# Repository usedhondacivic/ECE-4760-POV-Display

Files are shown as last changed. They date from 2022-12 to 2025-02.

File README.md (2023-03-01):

# ECE-4760 Final Project: Persistence of Vision Display
A persistence of vision display constructed from scratch using the Raspberry Pi Pico W microcontroller. Runs at 30 FPS with full RGB color and streams images over wifi.

Created by: Michael Crum (mmc323@cornell.edu), Joseph Horwitz (jah569@cornell.edu), Rabail Makhdoom (rm857@cornell.edu)

Read the write up: https://michael-crum.com/pov_display/

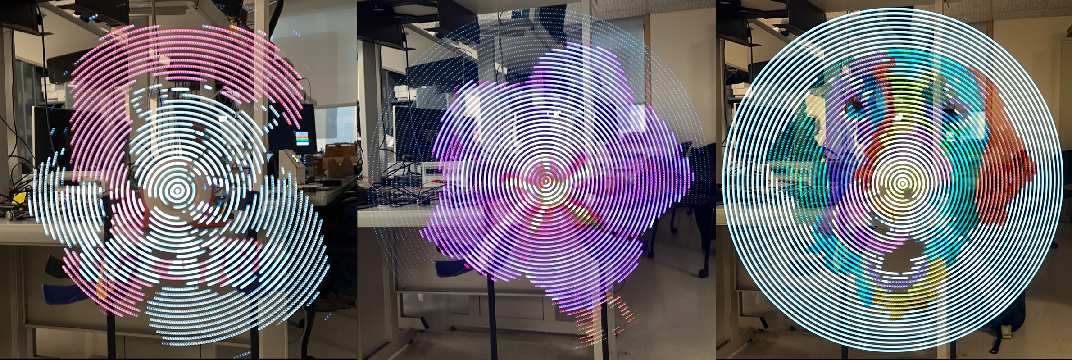
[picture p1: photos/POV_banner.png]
Three examples of the POV Display running


Project structure:
 - /PICO
	 - main.c
		 - Code entry point on the pico
	 - /drivers/apa102
		- Driver for the SPI based APA102 LEDs
	 - /utils/picow_tcp_client.c
		 - Driver for the TCP client
 - /PYTHON
	 - wifi.py
		 - TCP server for sending image data
- /new_python
	- New experimental python setup, including a browser based interface and support for most image types including gif's
	- web_server.py
		- Entry point for the program, launches the webserver which serves the web interface on localhost port 8080 (localhost:8080 in your web browser)
	- tcp_server.py
		- Handles connecting to the display over TCP, and sending arbitry data over the connection
	- file_translation.py
		- Translates image data to a radial RGB format used by the display
	- display_driver.py
		- Handles the transition from a file name to the proper byte format, then sends packets to the display using functions from tcp_server.py
	-  index.html
		- The html file served by the browser client in web_server.py

 - /HARDWARE
	 - /CAD
		 - STL files for 3D printing the mechanical structure
	 - /ELECTRICAL
		 - KiCad project files for the rotor and control board PCBs

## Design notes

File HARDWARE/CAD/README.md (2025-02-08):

Public onshape file is here: https://cad.onshape.com/documents/17b541f123296cb1e64515a7/w/77f36ce16f101784798e0ec6/e/821b7ccc222bb8b1a8efb6eb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

Fusion files are in super_structure.f3d

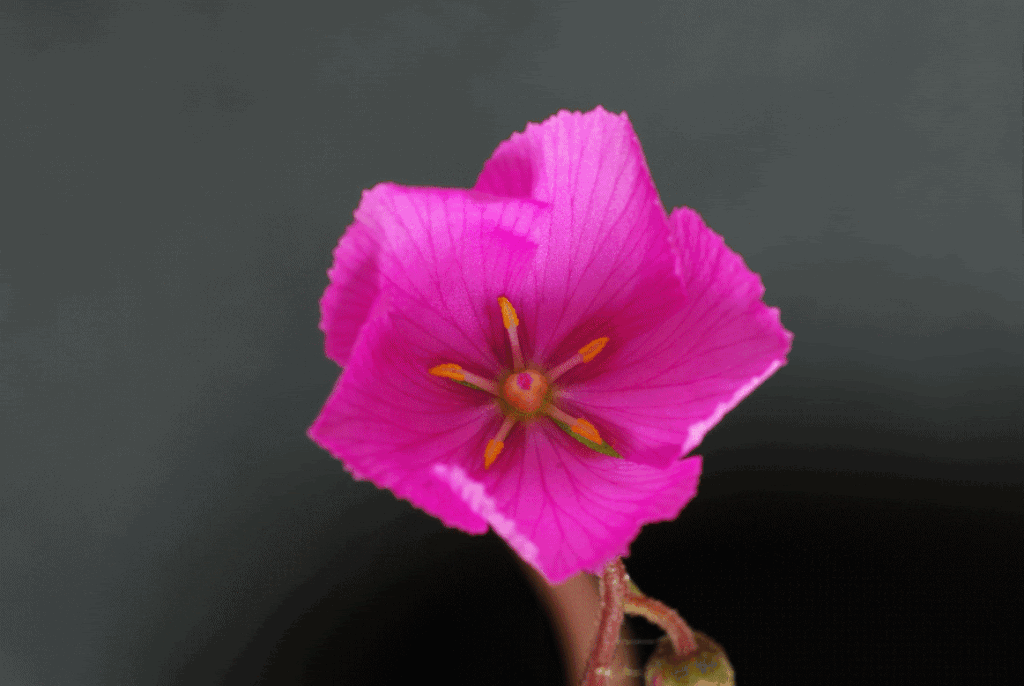
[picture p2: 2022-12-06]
PYTHON/pov_images/flower/original/frame_2_delay-0.2s.gif

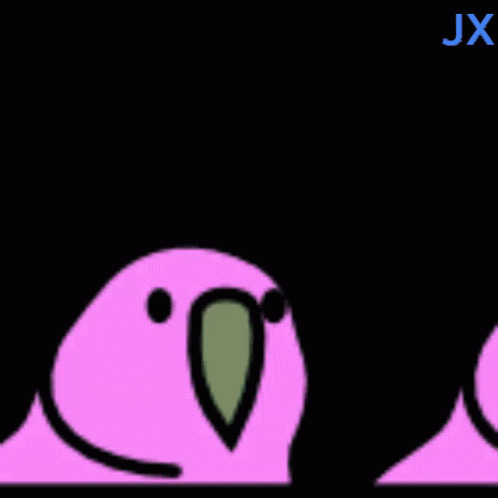
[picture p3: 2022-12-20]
PYTHON/pov_images/bird/frame-07-delay-005s.bmp

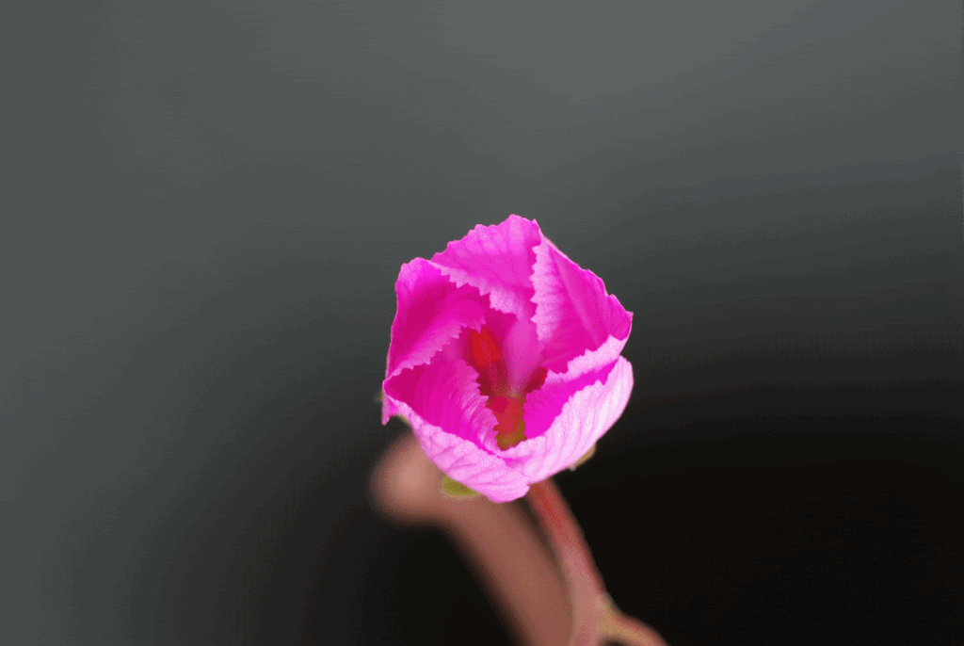
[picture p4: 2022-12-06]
PYTHON/pov_images/flower/original/frame_0_delay-0.2s.gif

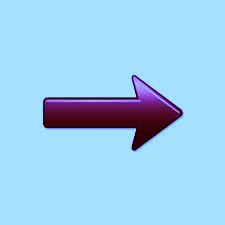
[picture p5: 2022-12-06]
PYTHON/pov_images/arrow.bmp

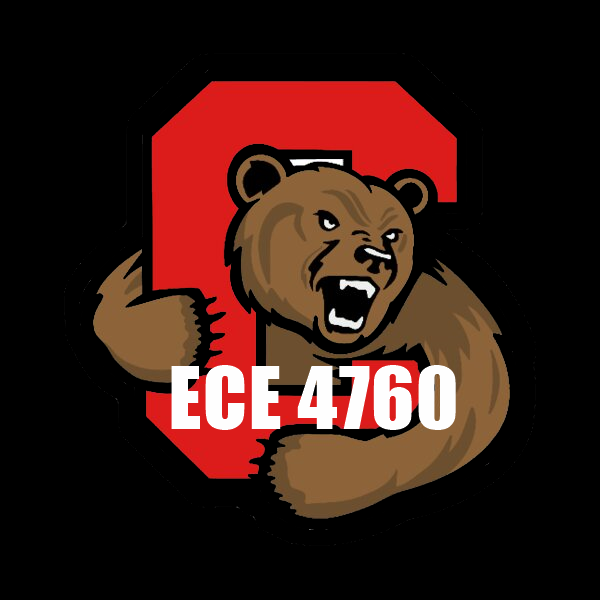
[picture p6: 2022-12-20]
new_python/bear.bmp

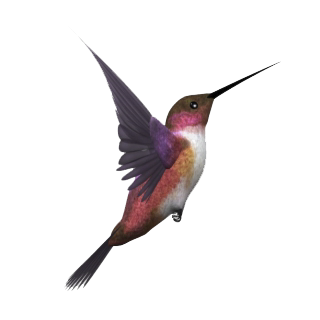
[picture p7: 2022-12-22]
new_python/bird.png

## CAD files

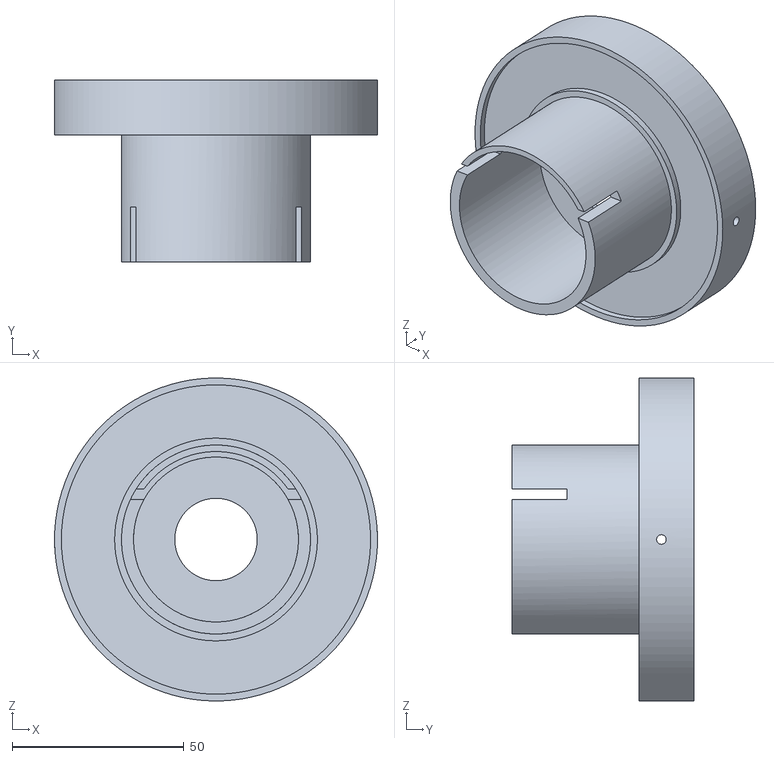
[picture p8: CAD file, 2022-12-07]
HARDWARE/CAD/POV_display_motor_mount.stl
94.0 x 53.0 x 94.0

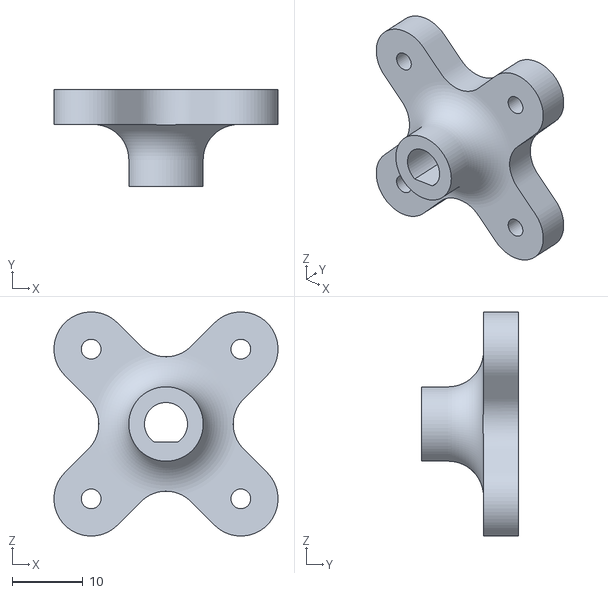
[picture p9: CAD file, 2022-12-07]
HARDWARE/CAD/POV_display_motor_adapter.stl
31.7 x 13.8 x 31.7

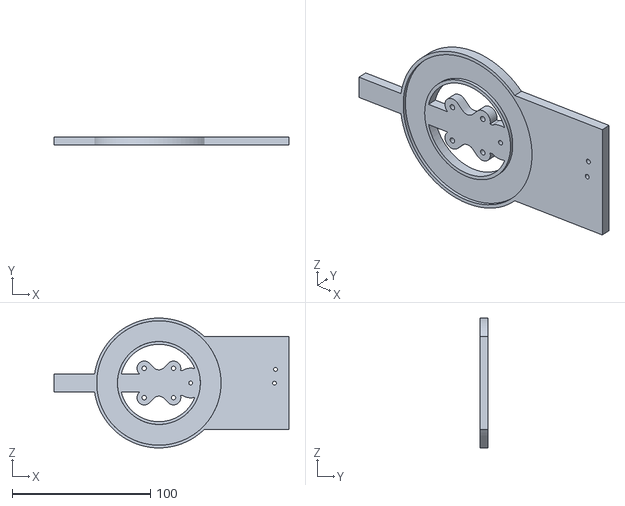
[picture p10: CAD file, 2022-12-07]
HARDWARE/CAD/POV_display_rotor.stl
170.1 x 6.00 x 94.0

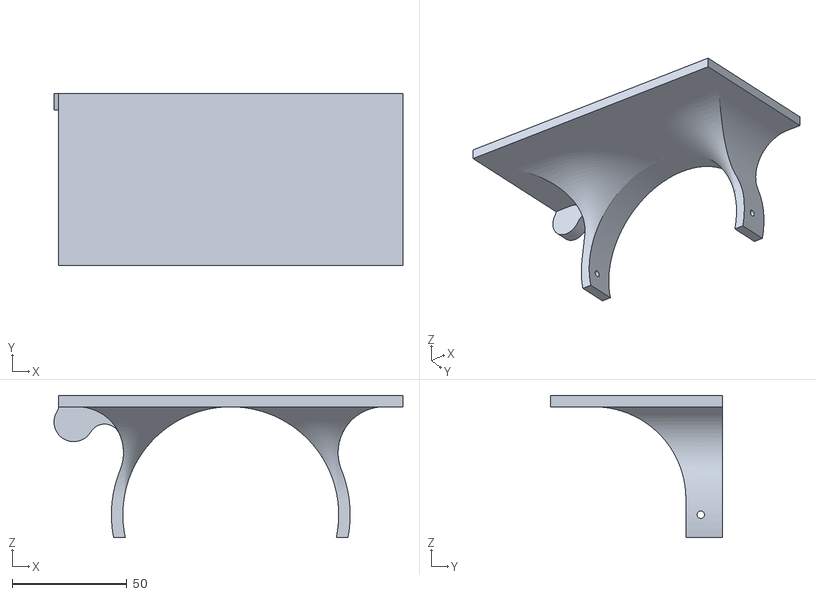
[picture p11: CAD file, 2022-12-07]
HARDWARE/CAD/POV_display_table_mount.stl
152.0 x 75.0 x 62.0

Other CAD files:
HARDWARE/CAD/super_structure.f3d

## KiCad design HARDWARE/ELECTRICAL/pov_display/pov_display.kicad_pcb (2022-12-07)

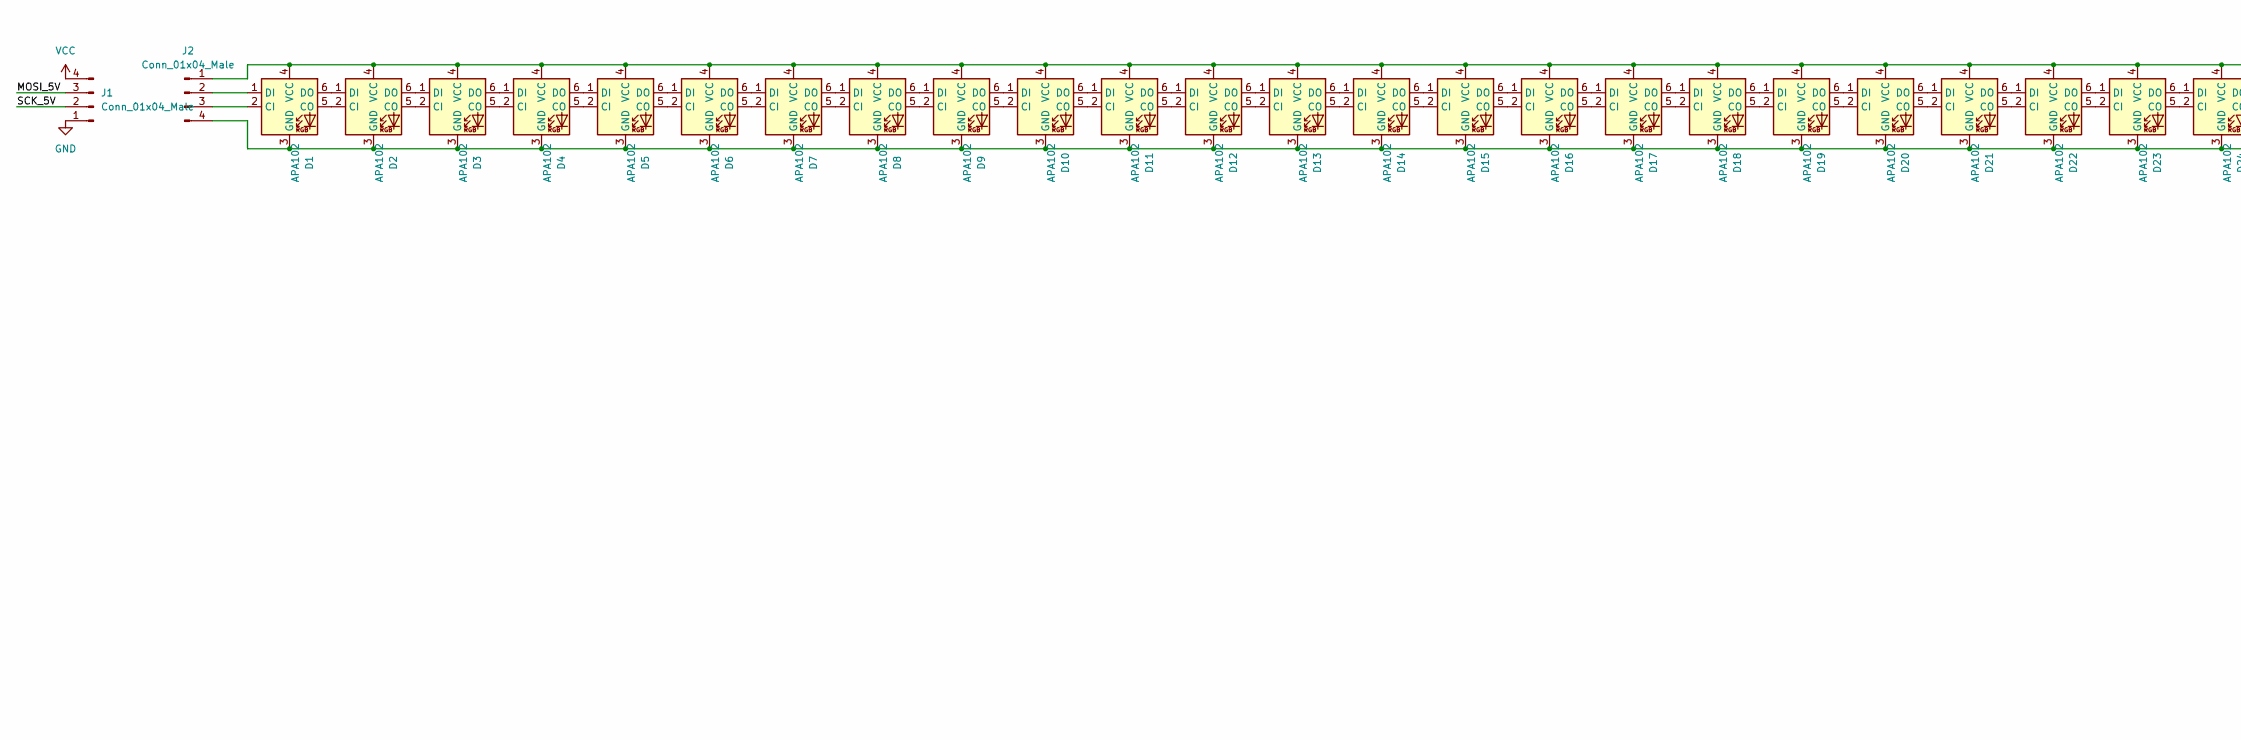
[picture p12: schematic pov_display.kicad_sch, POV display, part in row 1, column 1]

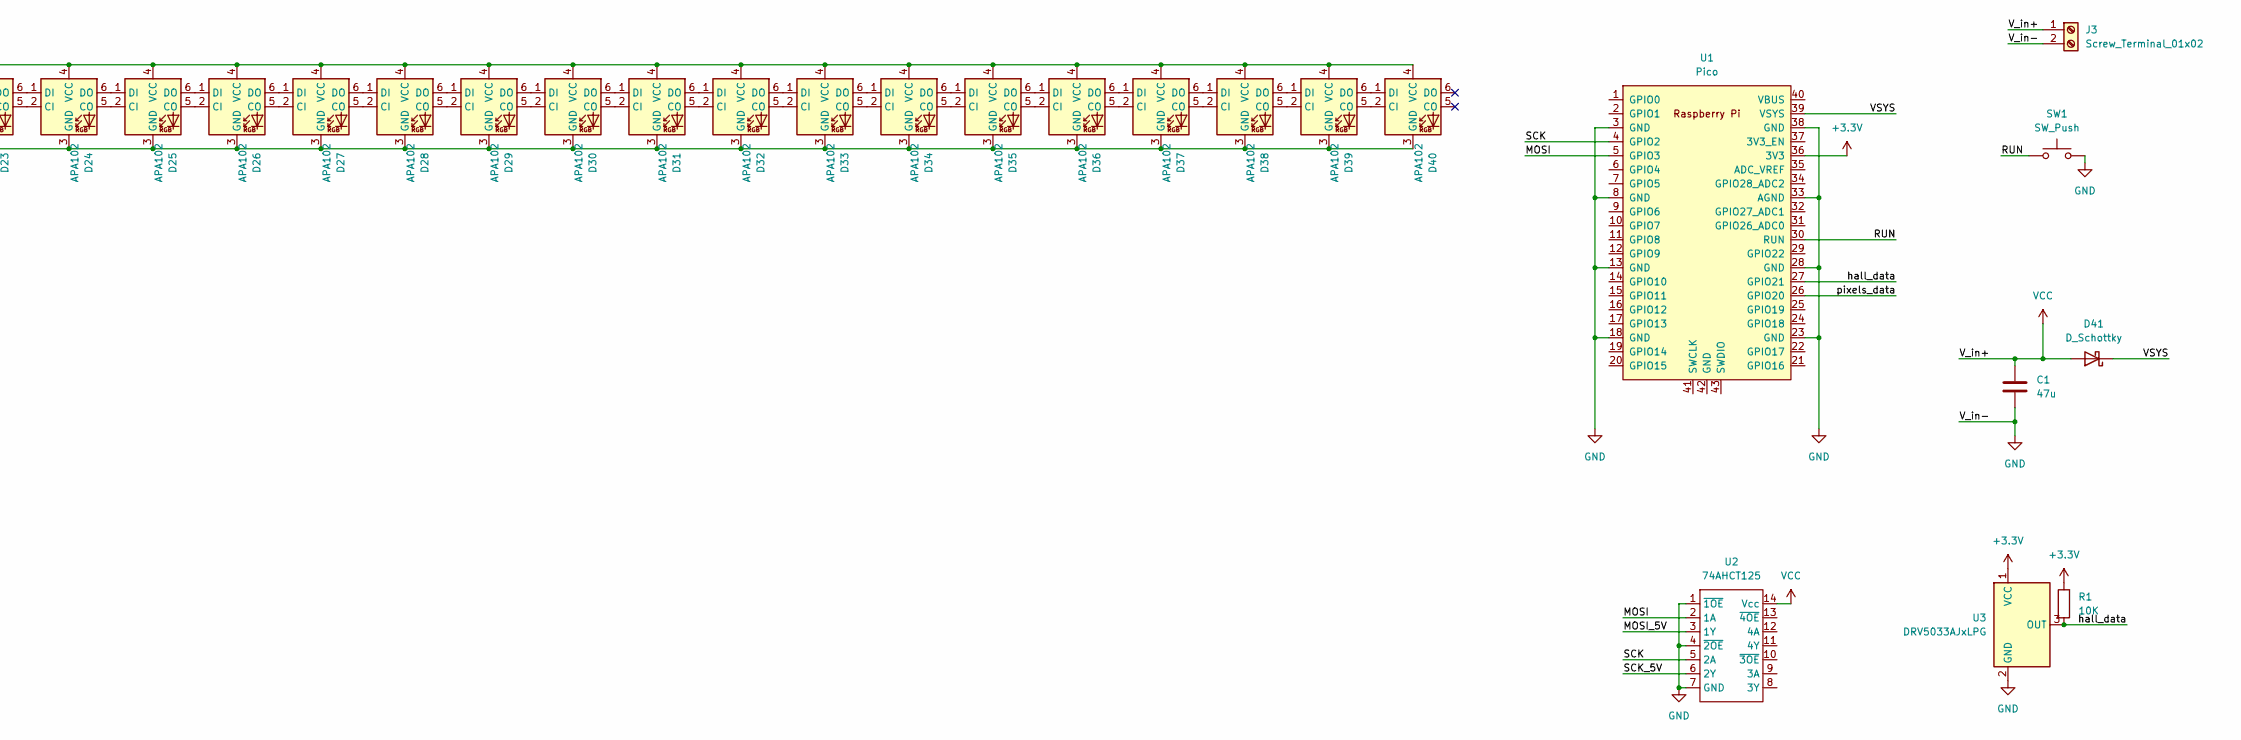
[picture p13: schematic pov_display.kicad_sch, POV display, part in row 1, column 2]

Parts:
C1: 47u; C_Rect_L7.0mm_W2.5mm_P5.00mm
D1, D2, D3, D4, D5, D6, D7, D8, D9, D10, D11, D12, D13, D14, D15, D16, D17, D18, D19, D20, D21, D22, D23, D24, D25, D26, D27, D28, D29, D30, D31, D32, D33, D34, D35, D36, D37, D38, D39, D40: APA102; LED_RGB_5050-6
D41: D_Schottky; D_DO-201AE_P3.81mm_Vertical_AnodeUp
J1, J2: Conn_01x04_Male; PinHeader_1x04_P2.54mm_Vertical
J3: Screw_Terminal_01x02; TerminalBlock_Phoenix_PT-1,5-2-5.0-H_1x02_P5.00mm_Horizontal
R1: 10K; R_Axial_DIN0207_L6.3mm_D2.5mm_P10.16mm_Horizontal
SW1: SW_Push; SW_PUSH_6mm
U1: Pico; RPi_Pico_SMD_TH
U2: 74AHCT125; 74AHCT125-PDIP
U3: DRV5033AJxLPG; TO-92_Inline_Wide

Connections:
+3.3V: R1.1, U1.36 (3V3), U3.1 (VCC)
/MOSI: U1.5 (GPIO3), U2.2 (1A)
/MOSI_5V: J1.3, U2.3 (1Y)
/RUN: SW1.1, U1.30 (RUN)
/SCK: U1.4 (GPIO2), U2.5 (2A)
/SCK_5V: J1.2, U2.6 (2Y)
/VSYS: D41.1 (K), U1.39 (VSYS)
/hall_data: R1.2, U1.27 (GPIO21), U3.3 (OUT)
/pixels_data: U1.26 (GPIO20)
GND: C1.2, J1.1, J3.2, SW1.2, U1.3 (GND), U1.8 (GND), U1.13 (GND), U1.18 (GND), U1.23 (GND), U1.28 (GND), U1.33 (AGND), U1.38 (GND), U2.1 (~1OE), U2.4 (~2OE), U2.7 (GND), U3.2 (GND)
unnamed: D1.1 (DI), J2.2
unnamed: D1.2 (CI), J2.3
unnamed: D1.3 (GND), D2.3 (GND), D3.3 (GND), D4.3 (GND), D5.3 (GND), D6.3 (GND), D7.3 (GND), D8.3 (GND), D9.3 (GND), D10.3 (GND), D11.3 (GND), D12.3 (GND), D13.3 (GND), D14.3 (GND), D15.3 (GND), D16.3 (GND), D17.3 (GND), D18.3 (GND), D19.3 (GND), D20.3 (GND), D21.3 (GND), D22.3 (GND), D23.3 (GND), D24.3 (GND), D25.3 (GND), D26.3 (GND), D27.3 (GND), D28.3 (GND), D29.3 (GND), D30.3 (GND), D31.3 (GND), D32.3 (GND), D33.3 (GND), D34.3 (GND), D35.3 (GND), D36.3 (GND), D37.3 (GND), D38.3 (GND), D39.3 (GND), D40.3 (GND), J2.4
unnamed: D1.4 (VCC), D2.4 (VCC), D3.4 (VCC), D4.4 (VCC), D5.4 (VCC), D6.4 (VCC), D7.4 (VCC), D8.4 (VCC), D9.4 (VCC), D10.4 (VCC), D11.4 (VCC), D12.4 (VCC), D13.4 (VCC), D14.4 (VCC), D15.4 (VCC), D16.4 (VCC), D17.4 (VCC), D18.4 (VCC), D19.4 (VCC), D20.4 (VCC), D21.4 (VCC), D22.4 (VCC), D23.4 (VCC), D24.4 (VCC), D25.4 (VCC), D26.4 (VCC), D27.4 (VCC), D28.4 (VCC), D29.4 (VCC), D30.4 (VCC), D31.4 (VCC), D32.4 (VCC), D33.4 (VCC), D34.4 (VCC), D35.4 (VCC), D36.4 (VCC), D37.4 (VCC), D38.4 (VCC), D39.4 (VCC), D40.4 (VCC), J2.1
unnamed: D1.5 (CO), D2.2 (CI)
unnamed: D1.6 (DO), D2.1 (DI)
unnamed: D2.5 (CO), D3.2 (CI)
unnamed: D2.6 (DO), D3.1 (DI)
unnamed: D3.5 (CO), D4.2 (CI)
unnamed: D3.6 (DO), D4.1 (DI)
unnamed: D4.5 (CO), D5.2 (CI)
unnamed: D4.6 (DO), D5.1 (DI)
unnamed: D5.5 (CO), D6.2 (CI)
unnamed: D5.6 (DO), D6.1 (DI)
unnamed: D6.5 (CO), D7.2 (CI)
unnamed: D6.6 (DO), D7.1 (DI)
unnamed: D7.5 (CO), D8.2 (CI)
unnamed: D7.6 (DO), D8.1 (DI)
unnamed: D8.5 (CO), D9.2 (CI)
unnamed: D8.6 (DO), D9.1 (DI)
unnamed: D9.6 (DO), D10.1 (DI)
unnamed: D9.5 (CO), D10.2 (CI)
unnamed: D10.5 (CO), D11.2 (CI)
unnamed: D10.6 (DO), D11.1 (DI)
unnamed: D11.5 (CO), D12.2 (CI)
unnamed: D11.6 (DO), D12.1 (DI)
unnamed: D12.5 (CO), D13.2 (CI)
unnamed: D12.6 (DO), D13.1 (DI)
unnamed: D13.5 (CO), D14.2 (CI)
unnamed: D13.6 (DO), D14.1 (DI)
unnamed: D14.5 (CO), D15.2 (CI)
unnamed: D14.6 (DO), D15.1 (DI)
unnamed: D15.5 (CO), D16.2 (CI)
unnamed: D15.6 (DO), D16.1 (DI)
unnamed: D16.5 (CO), D17.2 (CI)
unnamed: D16.6 (DO), D17.1 (DI)
unnamed: D17.5 (CO), D18.2 (CI)
unnamed: D17.6 (DO), D18.1 (DI)
unnamed: D18.5 (CO), D19.2 (CI)
unnamed: D18.6 (DO), D19.1 (DI)
unnamed: D19.5 (CO), D20.2 (CI)
unnamed: D19.6 (DO), D20.1 (DI)
unnamed: D20.5 (CO), D21.2 (CI)
unnamed: D20.6 (DO), D21.1 (DI)
unnamed: D21.5 (CO), D22.2 (CI)
unnamed: D21.6 (DO), D22.1 (DI)
unnamed: D22.5 (CO), D23.2 (CI)
unnamed: D22.6 (DO), D23.1 (DI)
unnamed: D23.5 (CO), D24.2 (CI)
unnamed: D23.6 (DO), D24.1 (DI)
unnamed: D24.5 (CO), D25.2 (CI)
unnamed: D24.6 (DO), D25.1 (DI)
unnamed: D25.5 (CO), D26.2 (CI)
unnamed: D25.6 (DO), D26.1 (DI)
unnamed: D26.5 (CO), D27.2 (CI)
unnamed: D26.6 (DO), D27.1 (DI)
unnamed: D27.5 (CO), D28.2 (CI)
unnamed: D27.6 (DO), D28.1 (DI)
unnamed: D28.5 (CO), D29.2 (CI)
unnamed: D28.6 (DO), D29.1 (DI)
unnamed: D29.5 (CO), D30.2 (CI)
unnamed: D29.6 (DO), D30.1 (DI)
unnamed: D30.5 (CO), D31.2 (CI)
unnamed: D30.6 (DO), D31.1 (DI)
unnamed: D31.5 (CO), D32.2 (CI)
unnamed: D31.6 (DO), D32.1 (DI)
unnamed: D32.5 (CO), D33.2 (CI)
unnamed: D32.6 (DO), D33.1 (DI)
unnamed: D33.5 (CO), D34.2 (CI)
unnamed: D33.6 (DO), D34.1 (DI)
unnamed: D34.5 (CO), D35.2 (CI)
unnamed: D34.6 (DO), D35.1 (DI)
unnamed: D35.5 (CO), D36.2 (CI)
unnamed: D35.6 (DO), D36.1 (DI)
unnamed: D36.5 (CO), D37.2 (CI)
unnamed: D36.6 (DO), D37.1 (DI)
unnamed: D37.5 (CO), D38.2 (CI)
unnamed: D37.6 (DO), D38.1 (DI)
unnamed: D38.5 (CO), D39.2 (CI)
unnamed: D38.6 (DO), D39.1 (DI)
unnamed: D39.5 (CO), D40.2 (CI)
unnamed: D39.6 (DO), D40.1 (DI)
VCC: C1.1, D41.2 (A), J1.4, J3.1, U2.14 (Vcc)

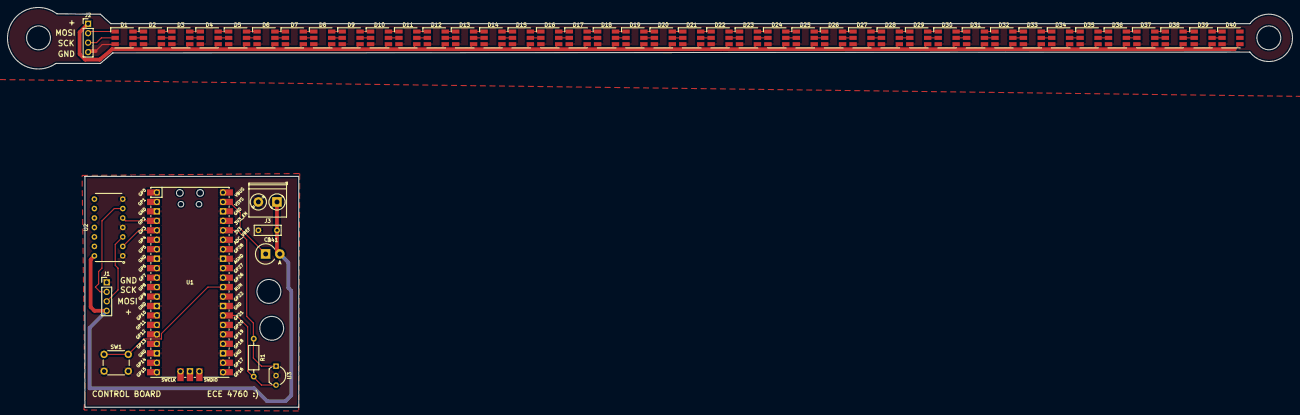
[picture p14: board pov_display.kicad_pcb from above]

Board: 2 copper layers, 345.0 x 16.5 mm, 50 parts (0 on the bottom side), 92 nets.

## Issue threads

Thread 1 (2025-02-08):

Design files for coil parts

Zufallsgenerat0r, 2025-02-08:
Hi and thanks for putting all the work here. Would you be able to include the original CAD design files since I bought a smaller coil and would like to scale the model accordingly.
Thanks in advance.

usedhondacivic, 2025-02-08:
No problem! I uploaded the fusion archive and also put the STEP files on OnShape. Take a look here: https://github.com/usedhondacivic/ECE-4760-POV-Display/tree/main/HARDWARE/CAD

Closed 2025-02-08.

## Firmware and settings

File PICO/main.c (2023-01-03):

#include <stdio.h>
#include "pico/stdlib.h"
#include "pico/divider.h"
#include "pico/multicore.h"

#include "hardware/gpio.h"
#include "hardware/pwm.h"
#include "hardware/uart.h"
#include "hardware/sync.h"

#include "hardware/clocks.h"
#include "hardware/pll.h"
#include "hardware/vreg.h"

#include <string.h>
#include <math.h>

#include "./drivers/apa102/apa102.h"
#include "./utils/pt_cornell_rp2040_v1.h"

#include "./drivers/hall_effect/hall_effect.h"

#define GPIO_IRQ_EDGE_RISE 0x8u
#define WS2812_PIN 2
#include "./utils/picow_tcp_client.h"

// WiFi Consts:
#define WIFI_SSID "CenturyLink9790"
#define WIFI_PASSWORD "e6baa5ee3c7f99"

volatile static unsigned int detect_time;
volatile static unsigned int old_time;
volatile static unsigned int time_period = 10000;
volatile static unsigned int curr_rot;

#define GPIO_PIN 21

int flag = 0;

volatile static unsigned int last_rise;

void gpio_fall(unsigned int gpio, uint32_t events)
{
    detect_time = time_us_32();

    if (detect_time - old_time > 10000)
    {
        time_period = detect_time - old_time;
        // printf("Detected \n");
        // printf("time_period: %u", time_period);

        old_time = detect_time;
        curr_rot = 0;
    }
    // reset_flag = 1;
    // last_zero_time = detect_time;
    // printf("Time: %d\n", time_period);
}

// void gpio_rise(unsigned int gpio, uint32_t events)
// {
//     last_rise = time_us_32();
// }

static PT_THREAD(protothread_timing(struct pt *pt))
{
    // Mark beginning of thread
    PT_BEGIN(pt);
    volatile static int begin_time;
    volatile static int spare_time;
    while (1)
    {
        // Measure time at start of thread
        begin_time = time_us_32();
        apa102_write_strip(led_array[curr_rot % ROTATIONS], LED_NUM);
        curr_rot++;
        unsigned int theta_time = time_period / ROTATIONS;
        spare_time = theta_time - (time_us_32() - begin_time);

        PT_YIELD_usec(spare_time);
    }
    PT_END(pt);
}

void core1_main()
{
    vreg_set_voltage(VREG_VOLTAGE_1_30);
    set_sys_clock_khz(250000, true);

    gpio_init(GPIO_PIN);
    gpio_set_dir(GPIO_PIN, 0);
    gpio_set_pulls(GPIO_PIN, true, false);

    gpio_set_irq_enabled_with_callback(GPIO_PIN, GPIO_IRQ_EDGE_RISE, 1, gpio_fall);
    gpio_set_irq_enabled_with_callback(GPIO_PIN, GPIO_IRQ_EDGE_FALL, 1, gpio_fall);

    apa102_init();

    uint8_t strip[LED_NUM][3] = {
        {255, 0, 0},
        {0, 255, 0},
        {0, 0, 0},
        {0, 255, 0},
        {255, 0, 0}};
    apa102_write_strip(strip, LED_NUM);

    // Add led timing thread
    pt_add_thread(protothread_timing);
    // //   Start the core 1 scheduler
    pt_schedule_start;
}

int main()
{
    stdio_init_all();

    if (cyw43_arch_init())
    {
        printf("failed to initialise\n");
        return 1;
    }
    cyw43_arch_enable_sta_mode();

    cyw43_arch_gpio_put(CYW43_WL_GPIO_LED_PIN, 1);

    printf("Connecting to WiFi...\n");
    if (cyw43_arch_wifi_connect_timeout_ms(WIFI_SSID, WIFI_PASSWORD, CYW43_AUTH_WPA2_AES_PSK, 30000))
    {
        printf("failed to connect.\n");
        return 1;
    }
    else
    {
        printf("Connected.\n");
        cyw43_arch_gpio_put(CYW43_WL_GPIO_LED_PIN, 0);
    }

    // cyw43_arch_deinit();

    // start core 1
    multicore_reset_core1();
    multicore_launch_core1(&core1_main);

    while (true)
    {
        if (run_tcp_client_test() == -1)
        {
            printf("FAILED\n");
        }
    }

    return 0;
}

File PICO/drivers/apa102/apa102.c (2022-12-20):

#include <stdio.h>
#include <stdlib.h>

#include "pico/stdlib.h"
#include "pico/binary_info.h"
#include "hardware/spi.h"

#include "apa102.h"

#define PIN_MISO 4
#define PIN_SCK 2
#define PIN_MOSI 3

#define SPI_PORT spi0

uint32_t start_marker = 0;
uint32_t end_marker = 0xFFFFFFFF;

void apa102_init()
{
    // This example will use SPI0 at 15MHz.
    spi_init(SPI_PORT, 20000 * 1000);
    gpio_set_function(PIN_MISO, GPIO_FUNC_SPI);
    gpio_set_function(PIN_SCK, GPIO_FUNC_SPI);
    gpio_set_function(PIN_MOSI, GPIO_FUNC_SPI);
    // Make the SPI pins available to picotool
    bi_decl(bi_3pins_with_func(PIN_MISO, PIN_MOSI, PIN_SCK, GPIO_FUNC_SPI));
}

void apa102_test()
{
    uint32_t led = 0xFFFF0000;
    uint32_t buf[] = {
        start_marker,
        led,
        end_marker};

    const uint8_t test_buf[] = {
        0x00,
        0x00,
        0x00,
        0x00,       // Start cond
        0b11111111, // Brightness
        0xFF,       // RED
        0x00,       // BLUE
        0x00,       // GREEN
        0b11110001, // Brightness
        0x00,       // RED
        0xFF,       // BLUE
        0x00,       // GREEN
        0b11110001, // Brightness
        0x00,       // RED
        0x00,       // BLUE
        0xFF,       // GREEN
        0xFF,
        0xFF,
        0xFF,
        0xFF // End cond
    };
    spi_write_blocking(SPI_PORT, test_buf, 16);
}

void apa102_write_strip(uint8_t (*color_data)[3], uint16_t num_leds)
{
    uint8_t spi_buffer[num_leds * 4 + 8];
    // Start frame
    spi_buffer[0] = 0x00;
    spi_buffer[1] = 0x00;
    spi_buffer[2] = 0x00;
    spi_buffer[3] = 0x00;
    // LED frames
    for (int i = 0; i < num_leds; i++)
    {
        if (i < 5) // Inner most LEDs move slower, so appear brighter. Lower their brightness
        {
            spi_buffer[i * 4 + 4] = 0b11100001; // Not full brightness so I don't kill my retinas
        }
        else
        {
            spi_buffer[i * 4 + 4] = 0b11100011; // Not full brightness so I don't kill my retinas
        }
        // APA102's we have are RBG instead of RGB,so flip the BG inputs here.
        spi_buffer[i * 4 + 5] = color_data[i][0];
        spi_buffer[i * 4 + 6] = color_data[i][2];
        spi_buffer[i * 4 + 7] = color_data[i][1];
    }
    // End frame
    spi_buffer[num_leds * 4 + 4] = 0xFF;
    spi_buffer[num_leds * 4 + 5] = 0xFF;
    spi_buffer[num_leds * 4 + 6] = 0xFF;
    spi_buffer[num_leds * 4 + 7] = 0xFF;

    spi_write_blocking(SPI_PORT, spi_buffer, num_leds * 4 + 8);
}

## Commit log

2022-11-02 updated build path added ws2812 driver
2022-11-02 Fixed ws2812 driver
2022-11-09 Add ECAD files
    [pov_display-B_Cu.gbl, pov_display-B_Mask.gbs, pov_display-B_Paste.gbp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]
2022-11-11 Added apa102 driver
2022-11-16 Working Hall Sensor
2022-11-18 Fixed merge issues Fixed bugs with apa driver
    [main.c]
2022-12-02 Fixed issue with tcp
    [apa102.c, main.c]
2022-12-04 Turn off PICO status LED
2022-12-06 Hall works!
2022-12-07 Updated schematic for correct silkscreen labels
    [pov_display-B_Cu.gbl, pov_display-B_Mask.gbs, pov_display-B_Paste.gbp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]
2022-12-07 Added 3D Print files
    [POV_display_motor_adapter.stl, POV_display_motor_mount.stl, POV_display_rotor.stl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]
2022-12-22 Fixed USB uart
2022-12-22 Better prints
2022-12-25 Remove debug prints to help framerate
2025-02-08 Add fusion archive of cad
    [super_structure.f3d]
